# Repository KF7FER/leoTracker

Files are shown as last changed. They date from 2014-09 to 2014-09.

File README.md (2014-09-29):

leoTracker
==========

Small AVR-based standalone APRS Tracker for [Trackuino](http://www.trackuino.org/)

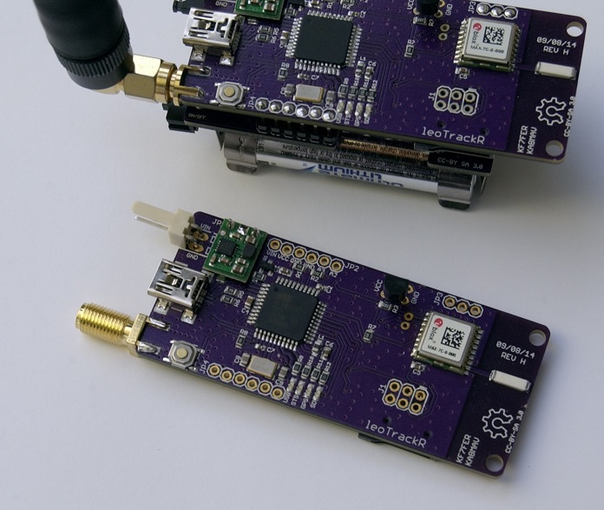
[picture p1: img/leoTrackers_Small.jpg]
leoTracker Front


This board was designed to be fairly inexpensive (BOM is $50 depending upon power source), small (1.25"x2.85"), light (under 17g depending upon configuration), and offer some features typically not available on other trackers.  

A ready to fly leoTracker (sans antenna) often weighs less than the power supply needed for other commercial APRS trackers.

Features include:

- ublox MAX-7/8 GPS w/ chip antenna
- Multiple Power options including boost converter (2xAA operation)
- Atmel (AVR) 32u4 Processor (same as in the Arduino Leonardo - hence the "leo")
- On-board USB for easy firmware updates
- microSD socket for data logging/board configuration
- DS18b20 temperature sensor (and connection for off-board sensor)
- NiceRF SA818 2m radio module (frequency agile; multiple power levels)

The leoTracker ONE
------------------

This is a test version of the leoTracker with an on-board single "AA" battery.  Testing has shown that despite running the SA818 just outside of the published specifications, the leoTracker will function correctly for 11+ hours.  It also has a few changes to support soldering the antenna directly to the PCB to reduce overall payload weight.

Status
--------

I just submitted the Revision "J" boards to fabrication and will post the results here.  The primary changes were a slightly changed footprint for the SA818; I changed the crystal footprint to match the part specified in the BOM (which actually has better low-temperature performance); and I cleaned up the silkscreen for fabrication.

Since those are very minor changes I don't expect any problems but I'll update this as soon as I get the boards back in my hands.

Firmware
--------
The firmware is available at [github.com/KF7FER/trackuino](https://github.com/KF7FER/trackuino). It is modified from the [John Boiles](https://github.com/johnboiles/trackuino) port in order to support the different pin mappings used on the leoTracker (as well as support of additional hardware).  This is, of course, based on EA5HAV's original [Trackuino](https://code.google.com/p/trackuino/)

Changes to the firmware include:

- Support for the ublox MAX-6/7/8 (switch to flight mode; use low power mode when possible)
- Support for the on-board microSD card (still a work in progress)
- Support for the Dallas DS18b20 temperature sensors (two are supported)
- Added support for the NiceRF SA818 radio module

I/O Pin Usage
--------
Here is a document listing I/O pin usage for the different leoTracker versions

leoTracker BOM

Powering the leoTracker
--------

The board may be powered by the following methods:

- Add-on TI TPS61202 Boost converter ([Pololu U1V10F3](http://www.pololu.com/product/2563)) on JP1
- 2xAA Boost converter board (files available w/ leoTracker)
- 3.3v LDO board (this is for vehicle/aircraft use) for 5-20v power sources
- A LiPoly/Solar board is currently under development

Bill of Materials
-----------------

The Bill of Materials is a bit out of date but should be fairly close

leoTracker BOM
2xAA Boost BOM

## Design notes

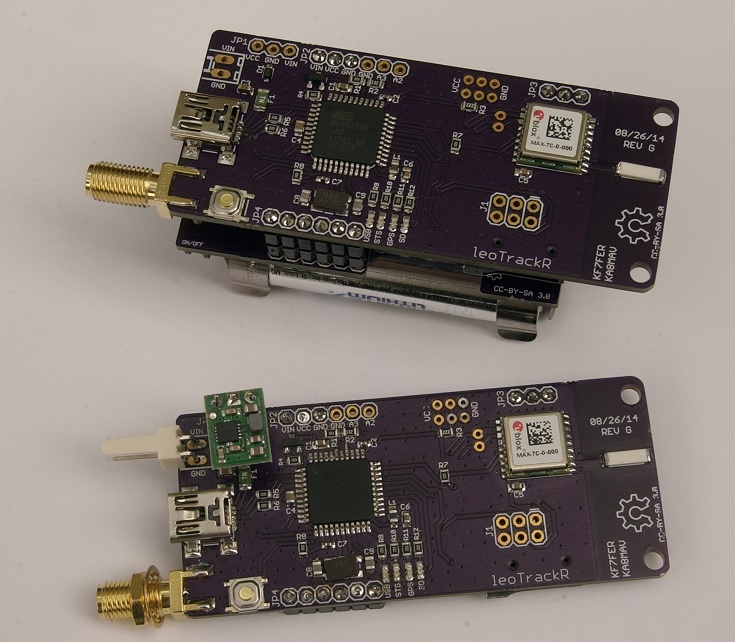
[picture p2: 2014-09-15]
img/leoTrackerRevG_FrontSmall.jpg

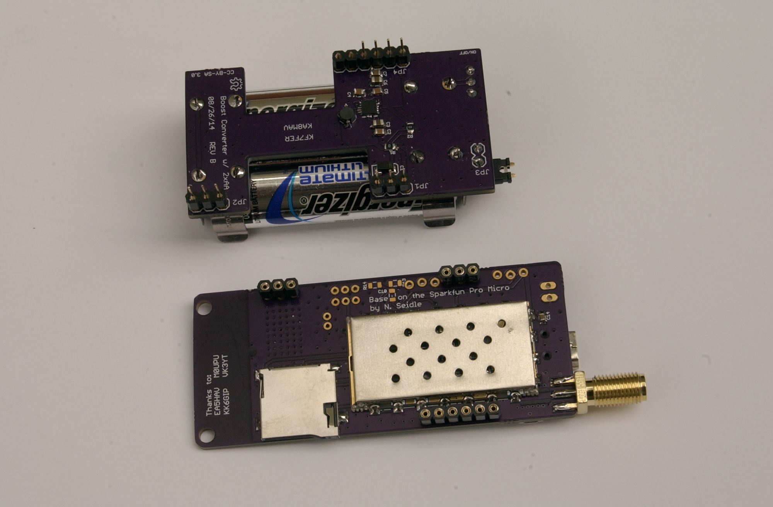
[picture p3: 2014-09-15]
img/leoTrackerRevG_Back.JPG

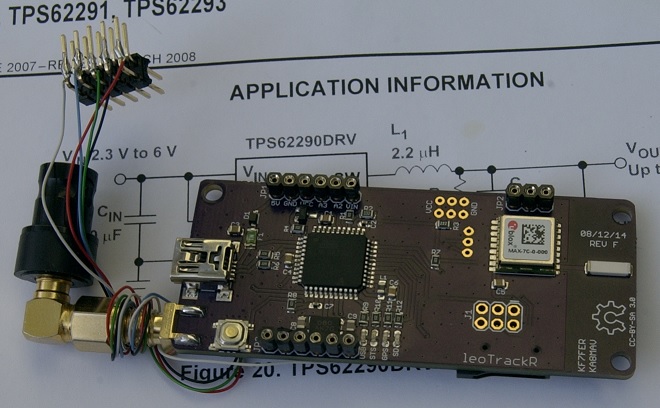
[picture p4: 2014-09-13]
img/leoFront.jpg

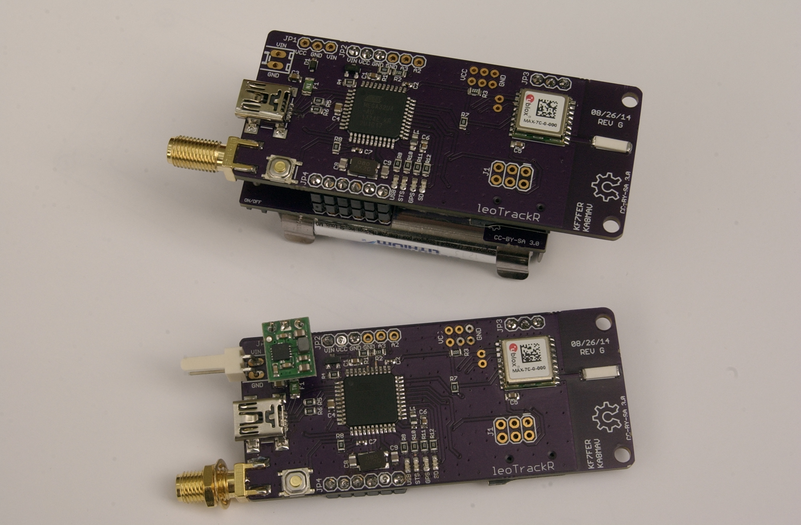
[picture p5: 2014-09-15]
img/leoTrackerRevG_Front.JPG

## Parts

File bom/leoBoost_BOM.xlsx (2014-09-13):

Part | Value | Vendor | PartNo | Temp | Cost
BAT1 | AA Battery | Sparkfun | PRT-07949 | *UNK* | 0.45
BAT2 | AA Battery | Sparkfun | PRT-07949 | *UNK* | 0.45
C1 | 47uF | Digikey | 511-1500-1-ND | -55 | 0.70
C2 | 0.1uF | Digikey | 399-1171-1-ND | -55 | 0.06
C3 | 10uF | Digikey | 1276-1764-1-ND | -55 | 0.12
C4 | 0.1uF | Digikey | 399-1171-1-ND | -55 | 0.06
C5 | 0.1uF | Digikey | 399-1171-1-ND | -55 | 0.06
C6 | 10uF | Digikey | 1276-1764-1-ND | -55 | 0.12
C7 | 1uF | Digikey | 399-10060-1-ND | -55 | 0.51
JP1 | 1x6 | Dipmicro | DE1556 |  | 0.25
JP2 | 1x3 | Dipmicro | DE1557 |  | 0.12
JP3 | 1x3 | Dipmicro | DE1562 |  | 0.12
JP4 | 1x2 | Dipmicro | DE1562 |  | 0.10
JP5 | 1x6 | Dipmicro | DE1562 |  | 0.25
L1 | 2.2uH | Mouser | 851-CDRH2D18HP-4R7NC | -40 | 0.68
R1 | 0 Ohm | Digikey | RHM0.0KTR-ND | -55 | 0.01
U1 | TPS61201 | Digikey | 296-21684-1-ND | -40 | 2.67
PCB |  | OSHPark |  |  | 4.90
TOTAL |  |  |  |  | 11.63

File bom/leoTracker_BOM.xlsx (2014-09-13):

Part | Value | Vendor | PartNo | Temp | Cost
C1 | 0.1uF | Digikey | 490-6327-1-ND | -55 | 0.01
C2 | 0.1uF | Digikey | 490-6327-1-ND | -55 | 0.01
C3 | 1uF | Digikey | 399-10060-1-ND | -55 | 0.51
C4 | 1uF | Digikey | 399-10060-1-ND | -55 | 0.51
C5 | 0.1uF | Digikey | 399-1171-1-ND | -55 | 0.06
C6 | 0.1uF | Digikey | 399-1171-1-ND | -55 | 0.06
C7 | 0.1uF | Digikey | 399-1171-1-ND | -55 | 0.06
C8 | 18pF | Digikey | 399-8030-1-ND | -55 | 0.03
C9 | 18pF | Digikey | 399-8030-1-ND | -55 | 0.03
C14 | 0.1uF | Digikey | 399-1171-1-ND | -55 | 0.06
D1 | BAS16SW | Digikey | BAS16WS-V-GS08CT-ND | -55 | 0.12
D2 | Amber | Digikey | 475-2712-1-ND | -40 | 0.18
D3 | Green | Digikey | 475-2920-1-ND | -40 | 0.19
D4 | Yellow | Digikey | 475-2794-1-ND | -40 | 0.17
D5 | Red | Digikey | 475-2761-1-ND | -40 | 0.18
F1 | 500mA PTC | Digikey | 283-3137-1-ND | -40 | 0.26
J$1 | SMA_EDGE | eBay |  |  | 0.50
JP1 | 1x06 | dipmicro | DE1556 |  | 0.25
JP2 | 1x03 | dipmicro | DE1557 |  | 0.25
JP3 | 1x06 | dipmicro | DE1563 |  | 0.10
L1 | MH2029-300Y (Bead) | Digikey | MH2029-300YCT-ND | -55 | 0.04
Q2 | NPN Transistor | Digikey | BC847BMTFCT-ND | *UNK* | 0.15
R1 | 10K | Digikey | P10KACT-ND | -55 | 0.01
R2 | 3K3 | Digikey | P3.3KACT-ND | -55 | 0.01
R3 | 4K7 | Digikey | P4.7KACT-ND | -55 | 0.01
R4 | 1K | Digikey | P1.0KACT-ND | -55 | 0.01
R5 | 22 Ohm | Digikey | P22ACT-ND | -55 | 0.01
R6 | 22 Ohm | Digikey | P22ACT-ND | -55 | 0.01
R7 | 10K | Digikey | P10KACT-ND | -55 | 0.01
R8 | 10K | Digikey | P10KACT-ND | -55 | 0.01
R9 | 330 Ohm | Digikey | P330ACT-ND | -55 | 0.01
R10 | 330 Ohm | Digikey | P330ACT-ND | -55 | 0.01
R11 | 330 Ohm | Digikey | P330ACT-ND | -55 | 0.01
R12 | 330 Ohm | Digikey | P330ACT-ND | -55 | 0.01
S1 | TAC_SWITCHSMD | Digikey | CKN9104CT-ND | -40 | 0.70
U$1 | ANTENNA2SMD6 | Digikey | 712-1003-1-ND | -40 | 1.05
U$2 | UBLOX_MAX | Hab Supplies | uBLOX MAX-M8Q | -40 | 17.00
U$5 | MicroSD Slot | dipmicro | DE1594 | *UNK* | 0.35
U$7 | SA818 | NiceRF | SA818 | -30 | 12.00
U3 | ATMEGA32U4 | Digikey | ATMEGA32U4-AU-ND | -40 | 5.23
X1 | USB-MINIB-5PIN | eBay | N/A |  | 0.50
Y1 | 8MHz | Digikey | 535-10630-1-ND | -40 | 1.30
PCB |  | OSHPark | N/A |  | 6.00
TOTAL |  |  |  |  | 47.98

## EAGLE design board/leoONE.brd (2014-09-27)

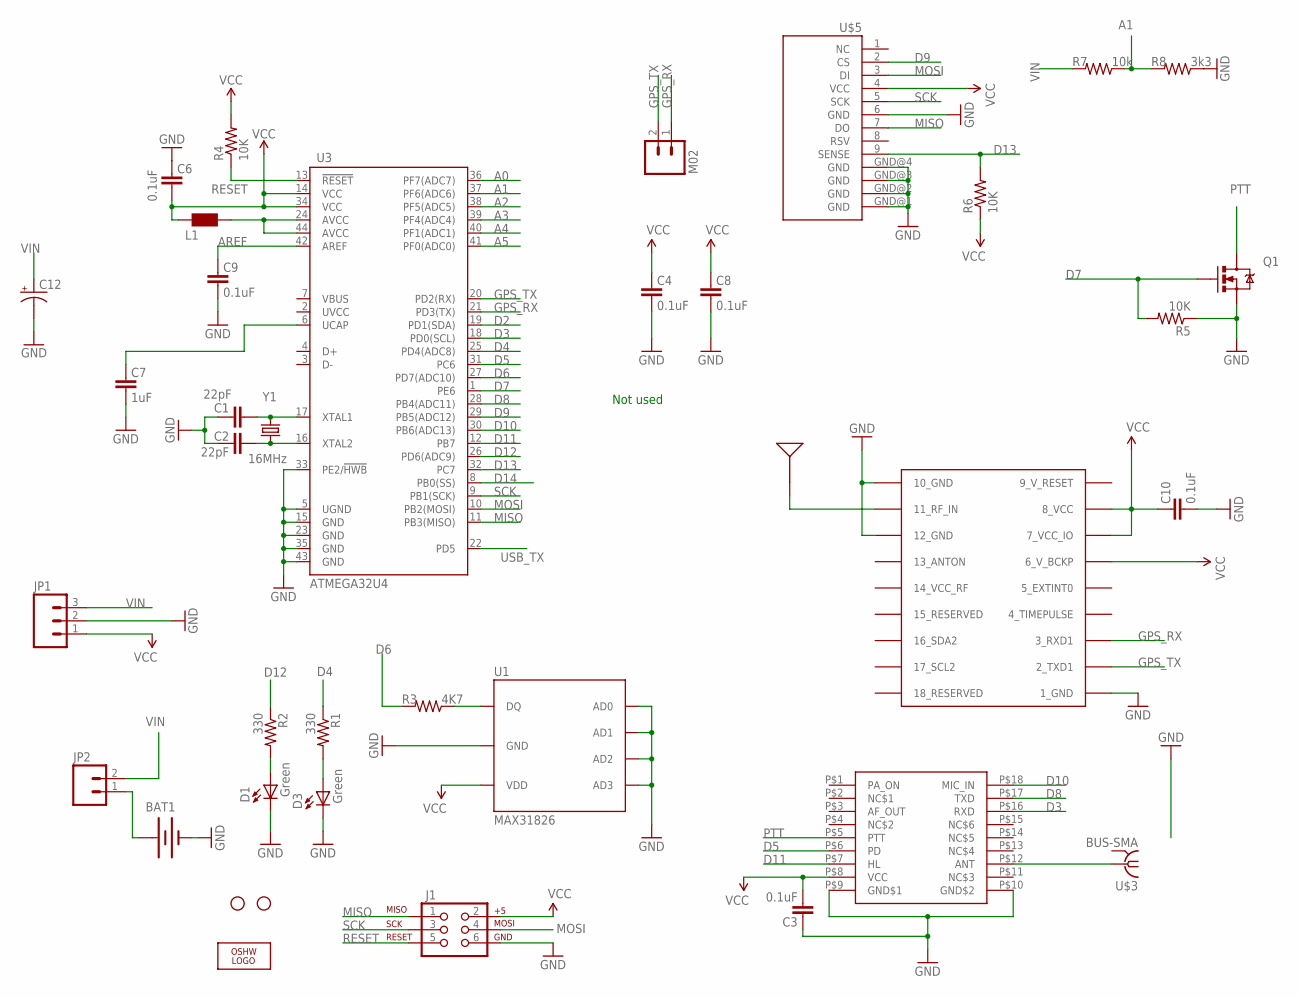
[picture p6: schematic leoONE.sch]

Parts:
BAT1: BATTERYAA; BATTERY-AA
C1, C2: 22pF; 0805
C3, C6, C9, C10: 0.1uF; 0805
C4, C8: 0.1uF; 0402-CAP
C7: 1uF; 0805
C12: CPOL-US153CLV-0405; 153CLV-0405
D1, D3: Green; LED-0603
J1: AVR_SPI_PRG_6PTH; 2X3
JP1: M03LOCK; 1X03_LOCK
JP2: M02LOCK; 1X02_LOCK
L1: MH2029-300Y; 0805
LOGO1: OSHW_LOGO_8MILX0200-NT; OSHW_8X200_NOTEXT
Q1: MOSFET-NCHANNELSMD; SOT23-3
R1, R2: 330; 0805
R3: 4K7; 0805
R4, R5, R6: 10K; 0805
R7: 10k; 0805
R8: 3k3; 0805
STANDOFF1, STANDOFF2: STAND-OFFTIGHT; STAND-OFF-TIGHT
U1: MAX31826; UMAX8
U3: ATMEGA32U4; SPARKFUN-DIGITALIC_TQFP44
U$1: ANTENNA2SMD6; ANTENNA-CHIP6
U$2: UBLOX_MAX
U$3: BUS-SMA
U$5: MICROSD_PI; MICROSD_PP
U$7: SA818
U$8: M02
Y1: 16MHz; ABRACON_ABM3_CRYSTAL

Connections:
9_V_RESET: U$2.9_V_RESET
A0: U3.36 (PF7(ADC7))
A1: R7.1, R8.2, U3.37 (PF6(ADC6))
A2: U3.38 (PF5(ADC5))
A3: U3.39 (PF4(ADC4))
A4: U3.40 (PF1(ADC1))
A5: U3.41 (PF0(ADC0))
AREF: C9.2, U3.42 (AREF)
D2: U3.19 (PD1(SDA))
D3: U3.18 (PD0(SCL)), U$7.P$16 (RXD)
D4: R1.1, U3.25 (PD4(ADC8))
D5: U3.31 (PC6), U$7.P$6 (PD)
D6: R3.2, U3.27 (PD7(ADC10))
D7: Q1.1 (G), R5.2, U3.1 (PE6)
D8: U3.28 (PB4(ADC11)), U$7.P$17 (TXD)
D9: U3.29 (PB5(ADC12)), U$5.2 (CS)
D10: U3.30 (PB6(ADC13)), U$7.P$18 (MIC_IN)
D11: U3.12 (PB7), U$7.P$7 (HL)
D12: R2.1, U3.26 (PD6(ADC9))
D13: R6.2, U3.32 (PC7), U$5.9 (SENSE)
D14: U3.8 (PB0(SS))
GND: BAT1.GND@1 (-), C1.2, C2.2, C3.2, C4.1, C6.2, C7.1, C8.1, C9.1, C10.1, C12.-, D1.C, D3.C, J1.6, JP1.2, Q1.2 (S), R5.1, R8.1, U1.4 (GND), U1.5 (AD0), U1.6 (AD1), U1.7 (AD2), U1.8 (AD3), U3.5 (UGND), U3.15 (GND), U3.23 (GND), U3.33 (PE2/!HWB), U3.35 (GND), U3.43 (GND), U$2.1_GND, U$2.10_GND, U$2.12_GND, U$3.2 (GND), U$3.3 (GND), U$3.4 (GND), U$3.5 (GND), U$5.6 (GND), U$5.GND@1 (GND), U$5.GND@2 (GND), U$5.GND@3 (GND), U$5.GND@4 (GND), U$7.P$9 (GND$1), U$7.P$10 (GND$2)
GPS_RX: U3.21 (PD3(TX)), U$2.3_RXD1, U$8.1
GPS_TX: U3.20 (PD2(RX)), U$2.2_TXD1, U$8.2
MISO: J1.1, U3.11 (PB3(MISO)), U$5.7 (DO)
MOSI: J1.4, U3.10 (PB2(MOSI)), U$5.3 (DI)
unnamed: C2.1, U3.16 (XTAL2), Y1.P$1 (1)
unnamed: C1.1, U3.17 (XTAL1), Y1.P$2 (2)
unnamed: R3.1, U1.2 (DQ)
unnamed: C7.2, U3.6 (UCAP)
unnamed: D3.A, R1.2
unnamed: BAT1.PWR@1 (+), JP2.1
unnamed: D1.A, R2.2
unnamed: U$1.1, U$2.11_RF_IN
unnamed: L1.2, U3.24 (AVCC), U3.44 (AVCC)
unnamed: U$3.1, U$7.P$12 (ANT)
PTT: Q1.3 (D), U$7.P$5 (PTT)
RESET: J1.5, R4.1, U3.13 (!RESET)
SCK: J1.3, U3.9 (PB1(SCK)), U$5.5 (SCK)
USB_TX: U3.22 (PD5)
VCC: C3.1, C4.2, C6.1, C8.2, C10.2, J1.2, JP1.1, L1.1, R4.2, R6.1, U1.1 (VDD), U3.14 (VCC), U3.34 (VCC), U$2.6_V_BCKP, U$2.7_VCC_IO, U$2.8_VCC, U$5.4 (VCC), U$7.P$8 (VCC)
VIN: C12.+, JP1.3, JP2.2, R7.2

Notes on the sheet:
Not used

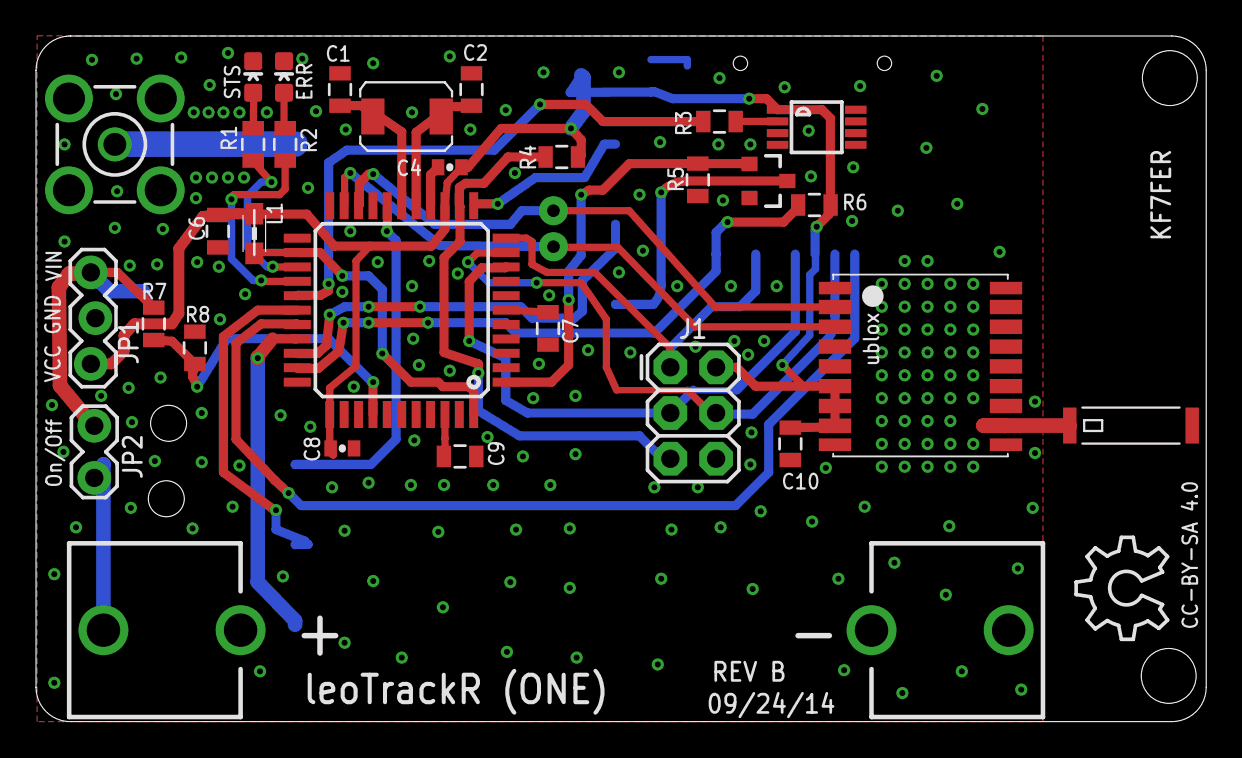
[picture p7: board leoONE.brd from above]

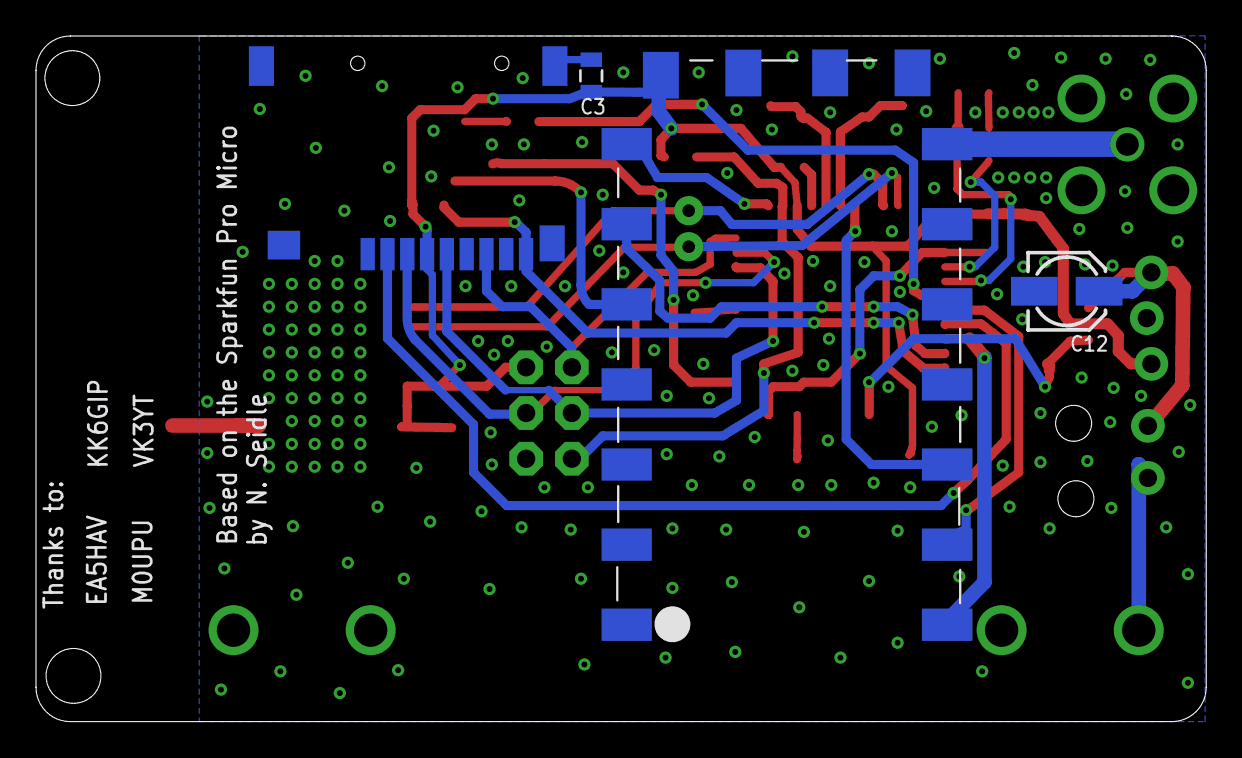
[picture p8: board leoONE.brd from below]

Board: 2 copper layers, 65.0 x 38.1 mm, 38 parts (4 on the bottom side), 33 nets.

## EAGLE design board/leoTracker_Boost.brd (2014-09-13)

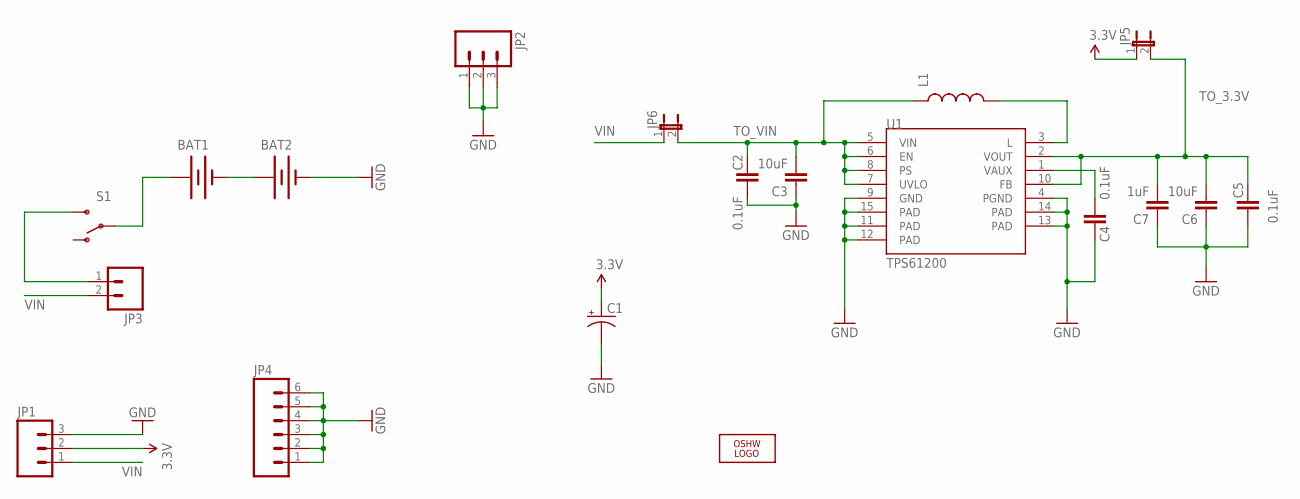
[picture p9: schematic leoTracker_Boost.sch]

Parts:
BAT1, BAT2: BATTERYAA; BATTERY-AA
C1: CAP_POL1206; EIA3216
C2, C4, C5: 0.1uF; 0805
C3, C6: 10uF; 0805
C7: 1uF; 0805
JP1, JP2: M03LOCK; 1X03_LOCK
JP3: M02LOCK; 1X02_LOCK
JP4: M06LOCK; 1X06_LOCK
JP5, JP6: JUMPER-2SMD-NC; SJ_2S
L1: INDUCTOR.; CDRH2D09
LOGO2: OSHW_LOGO_6MILX0100-NT; OSHW_6X100_NOTEXT
S1: SWITCH-SPDTPTH; SWITCH-SPDT
U1: TPS61200; QFN-10_PAD

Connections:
3.3V: C1.A (+), JP1.2, JP5.1
GND: BAT2.GND@1 (-), C1.C (-), C2.2, C3.1, C4.1, C5.2, C6.1, C7.1, JP1.3, JP2.1, JP2.2, JP2.3, JP4.1, JP4.2, JP4.3, JP4.4, JP4.5, JP4.6, U1.4 (PGND), U1.9 (GND), U1.11 (PAD), U1.12 (PAD), U1.13 (PAD), U1.14 (PAD), U1.15 (PAD)
unnamed: L1.P$2 (2), U1.3 (L)
unnamed: JP3.1, S1.3 (S)
unnamed: BAT1.GND@1 (-), BAT2.PWR@1 (+)
unnamed: BAT1.PWR@1 (+), S1.2
unnamed: C4.2, U1.1 (VAUX)
TO_3.3V: C5.1, C6.2, C7.2, JP5.2, U1.2 (VOUT), U1.10 (FB)
TO_VIN: C2.1, C3.2, JP6.2, L1.P$1 (1), U1.5 (VIN), U1.6 (EN), U1.7 (UVLO), U1.8 (PS)
VIN: JP1.1, JP3.2, JP6.1

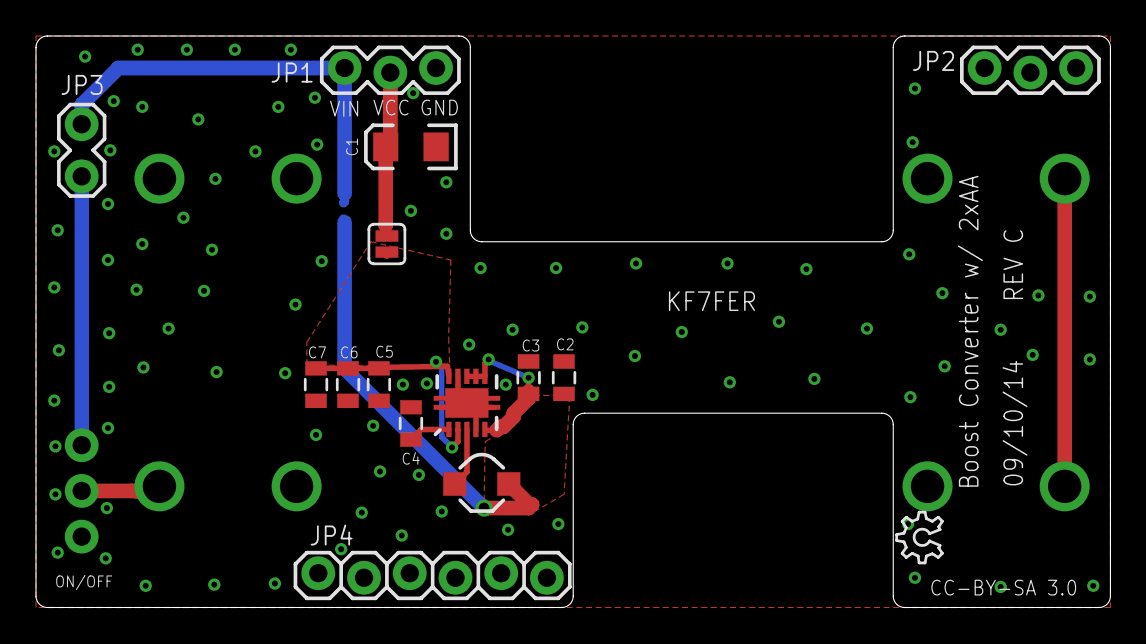
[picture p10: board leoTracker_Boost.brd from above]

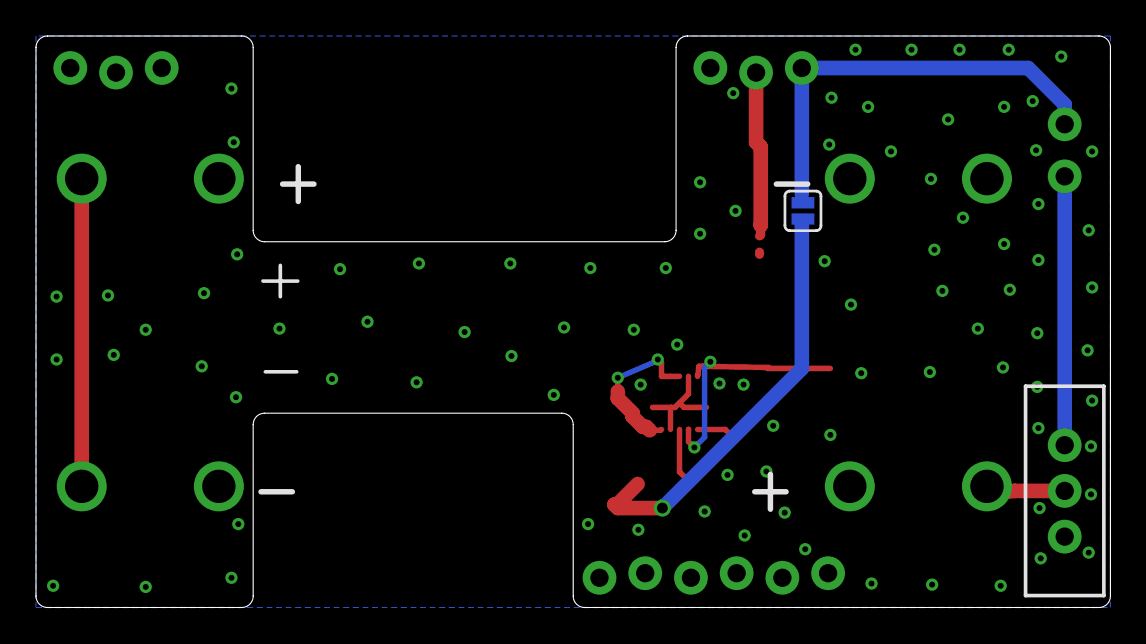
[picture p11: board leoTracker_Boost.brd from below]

Board: 2 copper layers, 59.7 x 31.8 mm, 19 parts (4 on the bottom side), 10 nets.

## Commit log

2014-09-13 Initial import w/ current Eagle files; started editing Readme.md
    [leoTracker.brd, leoTracker.sch, leoTracker_Boost.brd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]
2014-09-13 Initial check-in of current files
    Started w/ Rev "G" board and "C" boost boards as submitted to OSHPark.
2014-09-13 Added details about board/firmware
2014-09-13 Added BOM information
    [leoBoost_BOM.xlsx, leoTracker_BOM.xlsx]
2014-09-13 Added power info
2014-09-15 Initial check-in
    [PinDefs.xlsx]
2014-09-15 Added pin definitions; status section
2014-09-20 Minor correction to pad placement after latest board run
2014-09-27 Latest version: Used new SA818 footprint; changed crystal; cleaned up silkscreen for fabrication
    [leoTracker.brd, leoTracker.sch]
2014-09-27 Initial creation; untested
    [leoONE.brd, leoONE.sch]
2014-09-29 Added pics of new boards

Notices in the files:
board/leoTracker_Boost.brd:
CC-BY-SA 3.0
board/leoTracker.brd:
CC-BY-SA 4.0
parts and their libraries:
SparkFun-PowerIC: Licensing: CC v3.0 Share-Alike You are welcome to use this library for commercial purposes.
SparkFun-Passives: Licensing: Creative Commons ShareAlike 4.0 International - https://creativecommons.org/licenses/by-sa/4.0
